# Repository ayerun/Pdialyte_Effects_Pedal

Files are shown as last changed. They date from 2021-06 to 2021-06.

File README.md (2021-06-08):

# Pdialyte Effects Pedal
### Author: Arun Kumar
* Software and hardware design for a sound effect pedal with user created effects. See <a href="https://ayerun.github.io/Portfolio/Pdialyte.html" target="_blank">this portfolio post</a> for more information.

## Jetson Nano Setup
1. Install Dependencies
```
sudo apt install -y python3 git python3-pip
sudo apt update
sudo apt upgrade
sudo pip3 install --upgrade setuptools
sudo pip3 install adafruit-blinka
sudo pip install sparkfun-qwiic-twist 
sudo apt-get install puredata
```
2. Enable GPIO Pins
```
sudo /opt/nvidia/jetson-io/jetson-io.py
```
3. Set User Permissions
```
sudo groupadd -f -r gpio
sudo usermod -a -G gpio <insert_your_username>
```
4. Copy Udev Rules
```
cd ~
git clone https://github.com/NVIDIA/jetson-gpio.git
sudo cp ~/jetson-gpio/lib/python/Jetson/GPIO/99-gpio.rules /etc/udev/rules.d
```
5. Configure Pure Data DAC/ADC
    1. Plug in your USB audio interface
    2. Open Pure Data
    3. Media -> Audio Settings
    4. Set delay to 8ms
    5. Set input and output device to your audio interface
    6. Save All Settings
    7. Close Pd

## Wiring
* Encoder
    * 3.3V -> 3.3V
    * GND -> GND
    * SDA -> Jetson Pin 3
    * SCL -> Jetson Pin 5
* Stomp Button
    * Terminal 1 -> 1k Ohm Resistor -> 5V
    * Terminal 1 -> Jetson Pin 24
    * Terminal 2 -> GND
* LCD
    * Vss -> GND
    * Vdd -> 5V
    * V0 -> 10k Ohm Potentiometer Output
    * RS -> Jetson Pin 37
    * RW -> GND
    * E -> Jetson Pin 35
    * D4 -> Jetson Pin 22
    * D5 -> Jetson Pin 18
    * D6 -> Jetson Pin 15
    * D7 -> Jetson Pin 13
    * A -> 5V
    * K -> GND
* Potentiometer
    * Terminal 1 -> 5V
    * Terminal 2 -> V0 (LCD)
    * Terminal 3 -> GND

## Usage Instructions

1. Plug in Audio Interface
2. Launch effect
```
./<path_to_repo>/Effects_Library/<desired_sound_effect_directory>/start.sh
```

## Repository Layout
* CAD directory contains 3D models of the pedal
* Effects_Library contains all the sound effects
    * Each effect has its own folder
    * Each folder contains a controls.py, effect.pd, pedal_input~.pd, and start.sh file
        * effect.pd is the Pd patch with the sound effect
        * controls.py is the Python script that controls all pedal peripherals
        * pedal_input~.pd is a subpatch used in effect.pd to turn the sound effect on/off when the stomp button is pressed
            * inputs a 0 or 1
            * both outlets are the audio clean audio signal but only one outlet is on at a time.
        * start.sh is a bash script to start the sound effect

## Creating New Sound Effects
* Copy NEW_EFFECT_TEMPLATE directory
* Modify <a href="https://github.com/ayerun/Pdialyte_Effects_Pedal/blob/master/Effects_Library/NEW_EFFECT_TEMPLATE/controls.py" target="_blank">controls.py</a> with your effect parameters
    * There are detailed instructions in <a href="https://github.com/ayerun/Pdialyte_Effects_Pedal/blob/master/Effects_Library/NEW_EFFECT_TEMPLATE/controls.py" target="_blank">controls.py</a>
* Create an effect.pd patch
* See <a href="https://ayerun.github.io/Portfolio/Pdialyte.html" target="_blank">this portfolio post</a> for more details

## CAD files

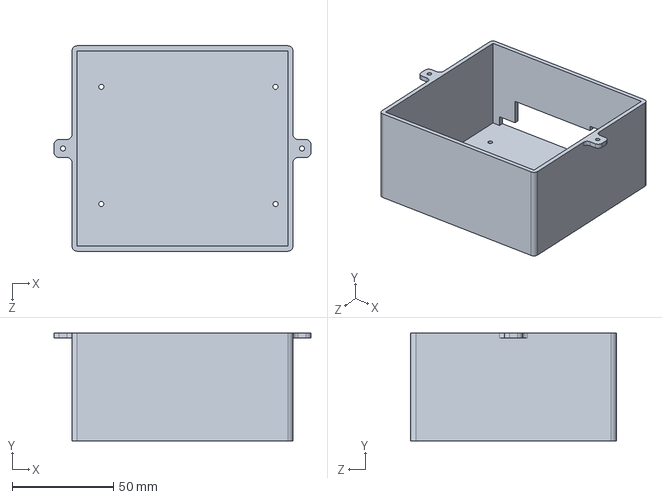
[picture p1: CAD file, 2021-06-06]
CAD/pedal_base.SLDPRT
127.0 x 53.3 x 101.6 mm

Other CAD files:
CAD/pedal_lid.DXF

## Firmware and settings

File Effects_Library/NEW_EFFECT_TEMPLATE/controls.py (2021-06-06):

'''
Template scipt for new sound effects for the Pdialyte Effects Pedal
If you are following my protocol you only need to modify the designated (by block comment) lines
'''

import time
import digitalio
import RPi.GPIO as GPIO
import adafruit_character_lcd.character_lcd as characterlcd
import board
import qwiic_twist
import sys
import os

class control:

    def __init__(self,title,low_lim,high_lim,unit,value=0):
        self.name = title
        self.unit = unit
        self.low = low_lim
        self.high = high_lim
        self.value = value

class controller:

    count = 0           #last encoder count
    clicked = False     #false while in control menu true while in tuning menu

    #constructor
    def __init__(self,controls):

        #Initialize Controls
        self.controls = controls
        self.control_index = 0
        self.control_lim = len(controls)-1

        #Initialize Button
        self.button = digitalio.DigitalInOut(board.D8)
        self.button_status = True

        #LCD Setup
        lcd_columns = 16
        lcd_rows = 2

        #GPIO Setup
        lcd_rs = digitalio.DigitalInOut(board.D26)
        lcd_en = digitalio.DigitalInOut(board.D19)
        lcd_d7 = digitalio.DigitalInOut(board.D27)
        lcd_d6 = digitalio.DigitalInOut(board.D22)
        lcd_d5 = digitalio.DigitalInOut(board.D24)
        lcd_d4 = digitalio.DigitalInOut(board.D25)
        lcd_backlight = digitalio.DigitalInOut(board.D4)

        #Initialize LCD
        self.lcd = characterlcd.Character_LCD_Mono(lcd_rs, lcd_en, lcd_d4, lcd_d5, lcd_d6, lcd_d7, lcd_columns, lcd_rows, lcd_backlight)
        self.lcd.backlight = True
        self.lcd.message = self.controls[0].name

        #Initialize Encoder
        self.twist = qwiic_twist.QwiicTwist()
        if self.twist.connected == False:
            print("The Qwiic twist device isn't connected to the system. Please check your connection", file=sys.stderr)
            sys.exit(0)
        self.twist.begin()
        self.twist.set_color(0, 255, 0) #set color to green
        self.twist.set_count(0)

        #Initialize Control Values
        for i in range(len(self.controls)):
            send2Pd(i,self.controls[i].value)
    
    #returns difference from last encoder count
    def getDiff(self):
        diff = self.twist.count-self.count
        self.count = self.twist.count
        if abs(diff) > 60000:
                diff = 0
        return diff

    #change encoder color between red and green
    def changeColor(self):
        red = self.twist.get_red()
        if red > 0:
            for i in range(256):
                self.twist.set_color(255-i,0+i,0)
                time.sleep(0.001)
        else:
            for i in range(256):
                self.twist.set_color(0+i,255-i,0)
                time.sleep(0.001)

    #check button status
    def buttonInterrupt(self):
        
        #check is pedal has been pressed
        if self.button.value == False:
            self.button_status = not self.button_status
            self.changeColor()
            time.sleep(0.4)
        
        #send 1 if pedal is on
        if self.button_status:
            send2Pd(99,1)
        
        #send 0 if pedal is off
        else:
            send2Pd(99,0)

def send2Pd(index, value):
    message = str(index) + ' ' + str(value) + ';'
    os.system("echo '" + message + "' | pdsend 3000")

def main():

    '''
    MODIFY THESE LINES
    You may Implement any number of controls

    example:
    control1 = control(title="Transposition",  low_lim=-24,    high_lim=24,    unit="1/2 steps",   value=0)
    control2 = control(title="Window",         low_lim=0,      high_lim=2000,  unit="ms",          value=100)
    control3 = control(title="Delay",          low_lim=0,      high_lim=5000,  unit="ms",          value=0)
    control4 = control(title="Wet",            low_lim=0,      high_lim=100,   unit="%",           value=50)
    control5 = control(title="Resolution",     low_lim=0,      high_lim=0,     unit="",            value=1)  #DO NOT CHANGE THIS LINE
    controls = [control1,control2,control3,control4,control5]   #resolution should always be last
    '''

    control1 = control(title="",            low_lim=0,  high_lim=0, unit="",    value=0)
    control2 = control(title="",            low_lim=0,  high_lim=0, unit="",    value=0)
    control3 = control(title="Resolution",  low_lim=0,  high_lim=0, unit="",    value=1) #DO NOT CHANGE THIS LINE
    controls = [control1,control2,control3]  #resolution should always be last

    '''
    In Pd:
    control1 will be sent to Pd in format '0 control_value' use route object accordingly
    control2 will be sent to Pd in format '1 control_value' use route object accordingly
    control3 will be sent to Pd in format '2 control_value' use route object accordingly
    control4 will be sent to Pd in format '3 control_value' use route object accordingly
    control5 (Resoltuion) will not be send to Pd
    The last output of the route object should be 99 connected to a pedal_input~ object for the stomp button toggle
    '''

    #Resolution
    res_list = [0.01,0.05,0.1,0.5,1,5,10,50,100]
    try:
        res_index = res_list.index(1)
    except:
        res_index = 0

    #Start controller
    ps = controller(controls)

    #Loop
    while True:

        #check for encoder ticks
        diff = ps.getDiff()
        if ps.twist.has_moved():

            #update control index and enforce limits
            ps.control_index += diff
            if ps.control_index < 0:
                ps.control_index = 0
            elif ps.control_index > ps.control_lim:
                ps.control_index = ps.control_lim
            
            #update lcd
            ps.lcd.clear()
            ps.lcd.message = ps.controls[ps.control_index].name

        #check for button press
        ps.buttonInterrupt()

        #check for encoder button press
        if ps.twist.was_clicked():
            ps.clicked = not ps.clicked

            #display tuning menu
            if ps.clicked:
                ps.lcd.message = ps.controls[ps.control_index].name + "\n" + str(ps.controls[ps.control_index].value) + " " + ps.controls[ps.control_index].unit

                #tuning menu
                while ps.clicked:

                    #resolution tune
                    if ps.control_index == len(ps.controls)-1:

                        #update value and enforce limits
                        diff = ps.getDiff()
                        if ps.twist.has_moved():
                            res_index += diff
                            if res_index > len(res_list)-1:
                                res_index = len(res_list)-1
                            elif res_index < 0:
                                res_index = 0
                            ps.controls[-1].value = res_list[res_index]

                            #update lcd
                            ps.lcd.clear()
                            ps.lcd.message = ps.controls[-1].name + "\n" + str(ps.controls[-1].value)


                    #control tune
                    else:

                        #update value and enforce limits
                        diff = ps.getDiff()
                        if ps.twist.has_moved():
                            ps.controls[ps.control_index].value += diff*ps.controls[-1].value
                            if ps.controls[ps.control_index].value < ps.controls[ps.control_index].low:
                                ps.controls[ps.control_index].value = ps.controls[ps.control_index].low
                            elif ps.controls[ps.control_index].value > ps.controls[ps.control_index].high:
                                ps.controls[ps.control_index].value = ps.controls[ps.control_index].high
                            
                            #update lcd
                            ps.lcd.clear()
                            ps.lcd.message = ps.controls[ps.control_index].name + "\n" + str(round(ps.controls[ps.control_index].value,2)) + " " + ps.controls[ps.control_index].unit

                            #send value to pd
                            send2Pd(ps.control_index, ps.controls[ps.control_index].value)
                    
                    #check for encoder button press
                    if ps.twist.was_clicked():
                        ps.clicked = not ps.clicked
                    
                    time.sleep(0.1)

                #remove value and display control menu
                ps.lcd.clear()
                ps.lcd.message = ps.controls[ps.control_index].name

        time.sleep(0.1)

if __name__ == '__main__':
	try:
		main()
	except (KeyboardInterrupt, SystemExit) as exErr:
		print("\nEnding Script")
		sys.exit(0)

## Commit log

2021-05-06 initial commit pitch shifter with qwerty keyboard and arduino gui need to integrate the pitch shifter with gui
2021-05-07 implemented custom communication protocol between Arduino and Pure Data
2021-05-12 added pitchshifter folder which contains pitchshifter with adc input
2021-05-19 added base scripts for encoder and lcd
2021-05-19 made controls.py added encoder and lcd to controls.py
2021-05-19 make controller object with encoder and lcd
2021-05-19 fixed bug in getDiff
    [controls.py]
2021-05-19 encoder color changes when menu changes
2021-05-19 fixed typo in changeColor pd file now routes data
    [controls.py]
2021-06-01 adding button testing
2021-06-01 fixed button_test but still errors
2021-06-01 deinitializing pin now
2021-06-01 made button into interrupt
2021-06-01 changed button pin
2021-06-01 button working!
2021-06-01 added button to controls.py
2021-06-01 added digitalio button_test
2021-06-01 integrated button using digitalio
2021-06-01 added button on/off
2021-06-01 encoder is green when effect is on and red when effect is off
2021-06-01 encapsulated pedal input and logic for button presses into pedal_input~.pd
2021-06-06 added README organized repo made controls_template added CAD files
    [pedal_base.SLDPRT, pedal_lid.DXF, pedal_lid.SLDPRT]
2021-06-06 fixed README typos and added NEW_EFFECT_TEMPLATE directory
    [controls.py]
